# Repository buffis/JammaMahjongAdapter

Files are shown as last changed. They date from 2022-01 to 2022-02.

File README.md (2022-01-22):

# JammaMahjongAdapter
 
Allows playing Mahjong PCBs on jamma wired cabinets.

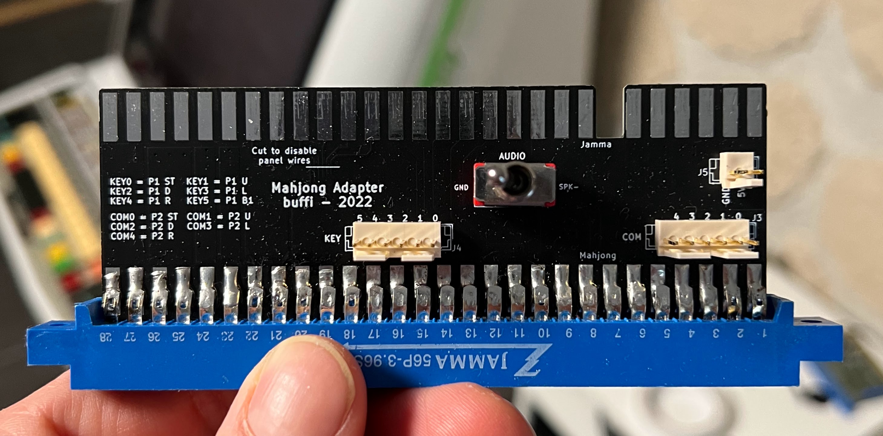
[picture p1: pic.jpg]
Finished adapter


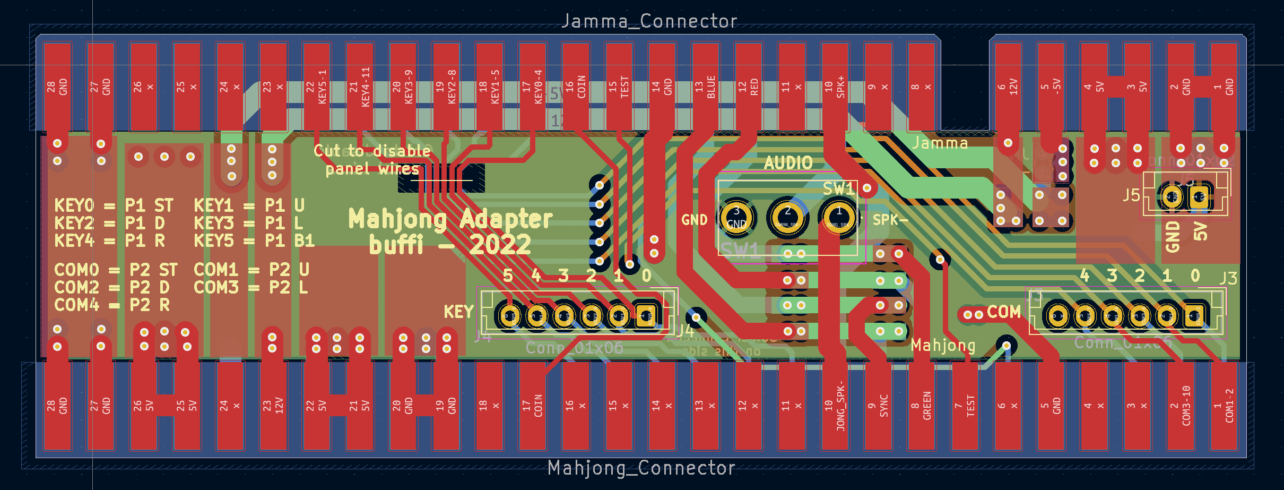
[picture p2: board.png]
Board


Note: Adapter above are missing some final touches present on cad files.

Features:
- Connectors for Mahjong COM and KEY pins
- KEY pins wired to P1 controls (see silkscreen)
- COM pins wired to P2 controls (see silkscreen)
- Switch for Mahjong AUDIO-. Either connects it to SPK- or GND, see note below.
- Optional jumper on the bottom for connecting -5V

Fabrication notes:
- This is a four layer PCB
- You might want gold finger finishing

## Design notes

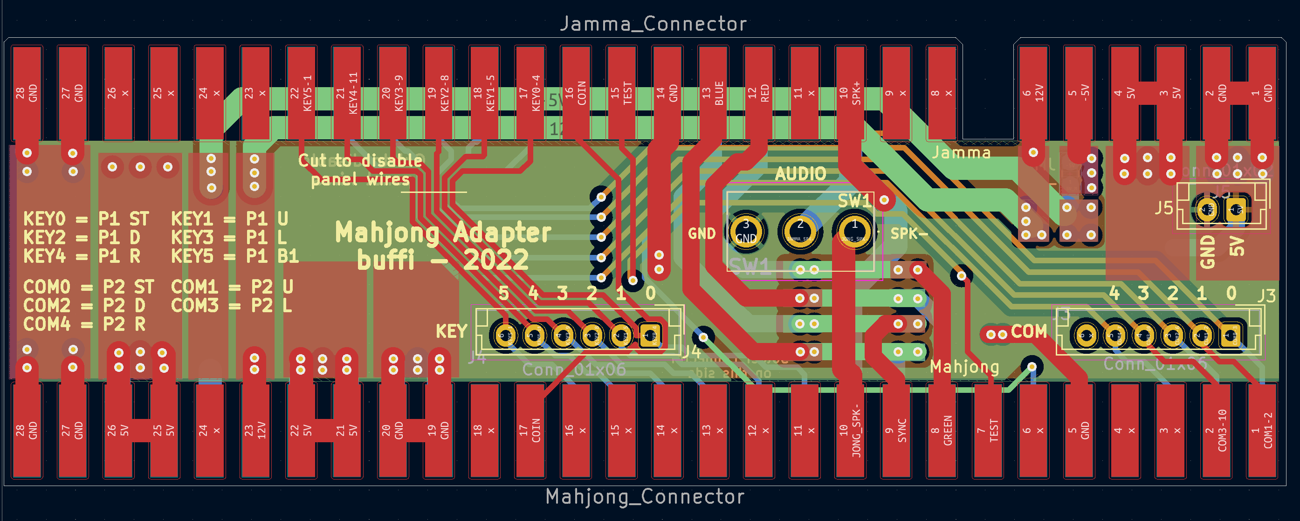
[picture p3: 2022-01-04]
jamma_mahjong/pic.png

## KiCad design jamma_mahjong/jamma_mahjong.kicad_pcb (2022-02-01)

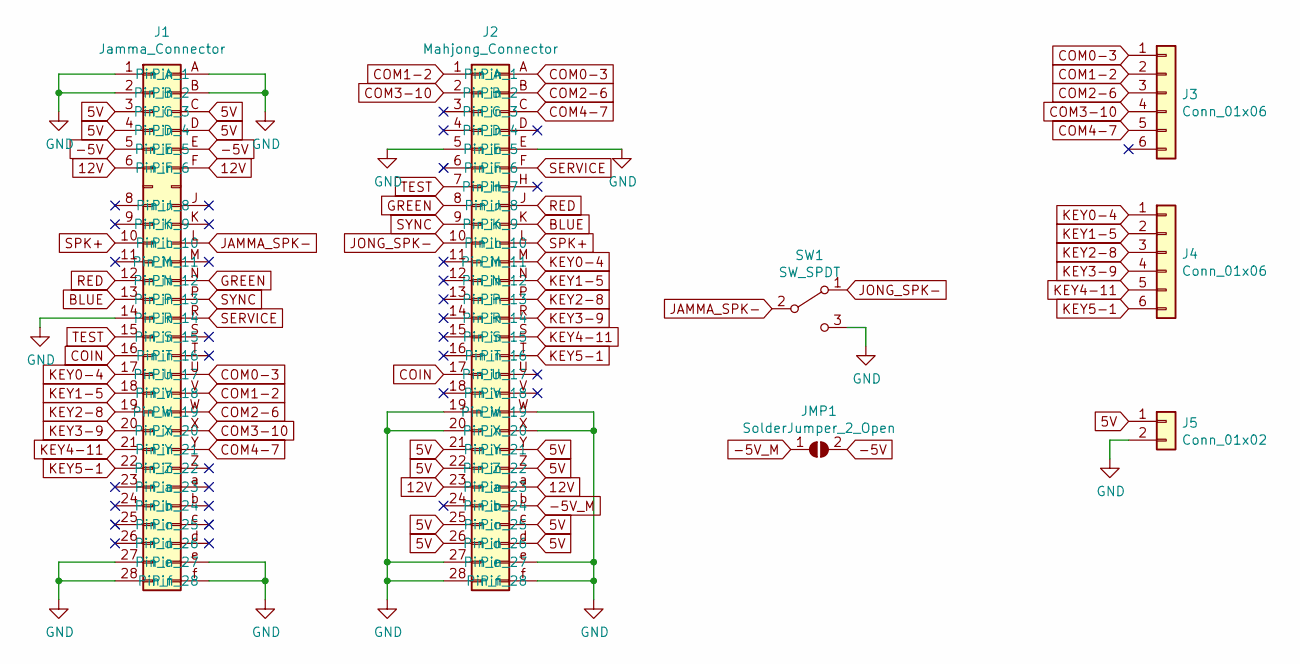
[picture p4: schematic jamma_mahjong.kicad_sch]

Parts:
J1: Jamma_Connector; JAMMA-56
J2: Mahjong_Connector; MAHJONG-56
J3, J4: Conn_01x06; JST_EH_B6B-EH-A_1x06_P2.50mm_Vertical
J5: Conn_01x02; JST_EH_B2B-EH-A_1x02_P2.50mm_Vertical
JMP1: SolderJumper_2_Open; R_0805_2012Metric_Pad1.20x1.40mm_HandSolder
SW1: SW_SPDT; A101SYCQ04

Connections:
5V: J1.3, J1.4, J1.C, J1.D, J2.21, J2.22, J2.25, J2.26, J2.Y, J2.Z, J2.c, J2.d, J5.1
12V: J1.6, J1.F, J2.23, J2.a
-5V: J1.5, J1.E, JMP1.2 (B)
-5V_M: J2.b, JMP1.1 (A)
BLUE: J1.13, J2.K
COIN: J1.16, J2.17
COM0-3: J1.U, J2.A, J3.1
COM1-2: J1.V, J2.1, J3.2
COM2-6: J1.W, J2.B, J3.3
COM3-10: J1.X, J2.2, J3.4
COM4-7: J1.Y, J2.C, J3.5
GND: J1.1, J1.2, J1.14, J1.27, J1.28, J1.A, J1.B, J1.e, J1.f, J2.5, J2.19, J2.20, J2.27, J2.28, J2.E, J2.W, J2.X, J2.e, J2.f, J5.2, SW1.3 (C)
GREEN: J1.N, J2.8
JAMMA_SPK-: J1.L, SW1.2 (B)
JONG_SPK-: J2.10, SW1.1 (A)
KEY0-4: J1.17, J2.M, J4.1
KEY1-5: J1.18, J2.N, J4.2
KEY2-8: J1.19, J2.P, J4.3
KEY3-9: J1.20, J2.R, J4.4
KEY4-11: J1.21, J2.S, J4.5
KEY5-1: J1.22, J2.T, J4.6
RED: J1.12, J2.J
SERVICE: J1.R, J2.F
SPK+: J1.10, J2.L
SYNC: J1.P, J2.9
TEST: J1.15, J2.7

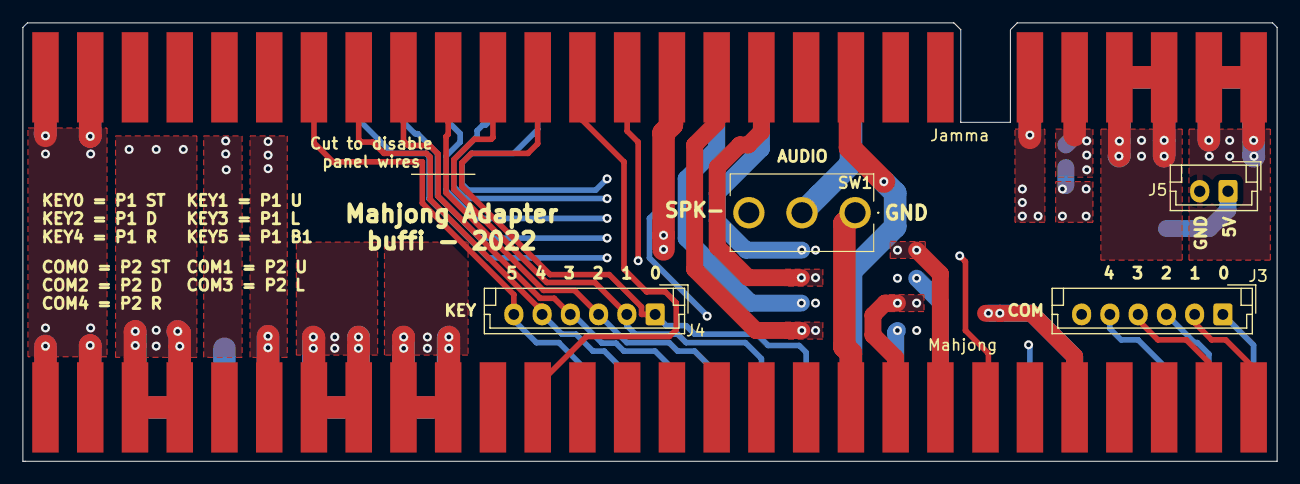
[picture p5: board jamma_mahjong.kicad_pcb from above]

Board: 4 copper layers, 111.0 x 38.8 mm, 7 parts (1 on the bottom side), 26 nets.

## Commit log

2022-01-22 More stuff
    [jamma_mahjong-B_Cu.gbl, jamma_mahjong-B_Mask.gbs, jamma_mahjong-B_Paste.gbp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]
2022-01-22 Remove soldermask from pin, add clearance under cuttable parts. Add image
    [jamma_mahjong.kicad_pcb]
2022-01-22 minor fixes, new gerbers
    [jamma_mahjong-B_Cu.gbl, jamma_mahjong-B_Mask.gbs, jamma_mahjong-B_Paste.gbp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]
2022-01-23 fix soldermask
    [jamma_mahjong.kicad_pcb]
2022-02-01 Fix silkscreen for SPK switcher (oops)
    [jamma_mahjong.kicad_pcb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]
2022-02-02 Minor fixes
    [jamma_mahjong-B_Cu.gbl, jamma_mahjong-B_Mask.gbs, jamma_mahjong-B_Paste.gbp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]
